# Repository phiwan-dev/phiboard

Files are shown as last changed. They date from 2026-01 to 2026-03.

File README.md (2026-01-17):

# phiboard
in progress, currently in the prototype phase...

# Third-Party Assets
### KiCad Symbols
The following Assets are from a third-party. Their original license still applies.
- Altium ISP1807-LR symbol in [`board/libraries/ISP1807-LR_Footprint.SchLib`](board/libraries/ISP1807-LR_Footprint.SchLib)
from the [manufacturers website](https://www.insightsip.com/products/bluetooth-le-modules/isp1807). There is no mention of a license.
- Kicad ISP1807-edit symbol in [`board/libraries/nordic-lib-kicad-isp1807.kicad_sym`](board/libraries/nordic-lib-kicad-isp1807.kicad_sym)
modified but based on the manufacturers symbol. Modifications follow this projects license (CERN-OHL-P-2.0).
- Kicad Nordic PMIC symbols in [`board/libraries/nordic-lib-kicad-npm.kicad_sym`](board/libraries/nordic-lib-kicad-npm.kicad_sym)
from https://github.com/hlord2000/nordic-lib-kicad using the CERN-OHL-P-2.0 license.
### KiCad Footprints
- Altium ISP1807-LR footprint in [`board/libraries/ISP1807-LR_Footprint.PcbLib`](board/libraries/ISP1807-LR_Footprint.PcbLib)
from the [manufacturers website](https://www.insightsip.com/products/bluetooth-le-modules/isp1807). There is no mention of a license.
- Kicad ISP1807-edit footprint in [`board/libraries/nordic-lib-kicad-isp1807.pretty`](board/libraries/nordic-lib-kicad-isp1807.pretty)
modified but based on the manufacturers symbol. Modifications follow this projects license (CERN-OHL-P-2.0).

<!-- ## Goals -->
<!-- - fully reversible pcb including hotswap sockets, MCU, OLED screen -->
<!-- - wireless using the XIAO BLE as MCU -->
<!-- - low profile (choc kailh) and thin PCB + components -->
<!-- - no visible screws from the top -->
<!-- - no visible seams from the top -->
<!-- - custom graphics and silk screen -->
<!-- - super easy, local zmk development -->

<!-- # Manual additions after Ergogen -->
<!-- Ergogen is used to generate most parts of the PCB. From within the ergogen folder, this can be done using: -->
<!-- ``` -->
<!-- ergogen . && cp output/pcbs/pcb.kicad_pcb ../kicad-prj/ -->
<!-- ``` -->
<!-- However, various smaller modifications as well as the reversible OLED and silkscreen graphics are placed manually by hand. -->
<!-- It is likely that this could be done through ergogen as well, feel free to fork and adjust my config. -->
<!-- All modifications are listed in here: -->
<!-- - Removed silksceens from diodes and modified silksceen for the battery pads. Be careful with this, as it make messing up the diode configuration very easy! -->
<!-- - Wired up MCU and keys in a reversible fashion -->
<!-- - Included reversible OLED --> 
<!-- - Put on silkscreens on front [`porsche-front-big.kicad_mod`](./kicad-prj/graphics.pretty/porsche-front-big.kicad_mod) and back [`porsche-back-big.kicad_mod`](./kicad-prj/graphics.pretty/porsche-back-big.kicad_mod) -->

<!-- # Customize Graphics -->
<!-- In [graphics](./kicad-prj/graphics/) you can find the source images used in this project. -->
<!-- There are two types of graphics. -->
<!-- ### Silkscreen -->
<!-- The silksceen uses the porsche images. -->
<!-- To use a different image you have to open `kicad > image converter`. -->
<!-- In here you can load your desired image, choose an output size and threshold and save it as footprint on F.Silkscreen. -->
<!-- In order for KiCad to detect your custom footprints, you have to save them to a folder with the extension `.pretty` like in [`kicad-prj/graphics.pretty/`](./kicad-prj/graphics.pretty/). -->
<!-- Lastly you need to tell KiCad where to find your footprints. -->
<!-- If you decide to use my project and its `graphics.pretty` folder then KiCad should automatically pick it up through the `fp-lib-table`. -->
<!-- Else, you can specify your `.pretty` path in `Preferences > Manage Footprint Libraries... > Project Specific Libraries`. -->
<!-- ### Solder Images -->
<!-- In the palm of the hand there is a little empty space on the PCB which I decided to use with images which are printed on there using solder. -->
<!-- I got the idea from [this video](https://www.youtube.com/watch?v=ohu4tZ4qov8). -->
<!-- Here is the workflow to put your own images on there: -->
<!-- You will most likely have a .png or .jpg image, which needs to be transformed to .svg. -->
<!-- For this you can use popular online tools like [convertio.co](https://convertio.co/). -->
<!-- Optionally you can try to optimize your svg using [this website](https://optimize.svgomg.net/), although it didn't make much of a difference for me. -->
<!-- Next, we need to transform our svg into an array of points, for which i used [this website](https://shinao.github.io/PathToPoints/). -->
<!-- Lastly, you can replace the point array in [`ergogen/footprints/phi-caps`](./ergogen/footprints/phi-caps.js) for the front side or [`ergogen/footprints/phi-logo`](./ergogen/footprints/phi-logo.js) for the back side. -->

<!-- # Parts -->
<!-- 40 keys, 20 per side -->
<!-- - 40 choc kailh switches -->
<!-- - 40 choc kailh keycaps -->
<!-- - 40 choc hotswap sockets -->
<!-- - 40 smd diodes 1N4148 -->
<!-- - 2 xiao ble -->
<!-- - 2 oled 0.91 inch i2c (optional) -->
<!-- - 2 batteries 3.7v (optional, requres cable otherwise) -->

<!-- # Firmware -->
<!-- Usually ZMK is compiled throug a GitHub actions workflow. However, I prefer to use it locally using a docker devcontainer. The devcontainer is provided by the official ZMK project. -->

<!-- ## Setting up the ZMK docker toolchain -->
<!-- ```bash -->
<!-- nix develop     # or install devcontainer cli otherwise -->
<!-- cd <path-to-phiboard>/firmware -->
<!-- ./setup-zmk.sh  # this may take a while -->
<!-- ``` -->

<!-- ## Compiling the ZMK firmware -->
<!-- ```bash -->
<!-- nix develop     # or install devcontainer cli otherwise -->
<!-- cd <path-to-phiboard>/firmware -->
<!-- ./build.sh  # clean build, is needed the first time -->
<!-- ./build.sh --cached   # faster, if a build has been done before -->
<!-- # the firmware is now located at <path-to-phiboard>/firmware/(left|right).uf2 -->
<!-- ``` -->

<!-- ## Flashing the firmware -->
<!-- - connect mcu with pc -->
<!-- - double press the reset button -->
<!-- - the file explorer should now show a usb media -->
<!-- - copy the corresponding .uf2 firmware to the usb media -->
<!-- - it should now auto-eject and run the new firmware -->

<!-- ## Fighting with ZMK -->
<!-- - spend a lot of time on local toolchain and scripts -->
<!-- - other projects may have their config files in different places -->
<!-- - explain most important files which the user might want to change (and where) -->
<!-- - confusing, overwhelming (at first) -->
<!-- - flash reset firmware to fix problems -->
<!-- - dtsi is "weird" because of the way the matrix is connected (only on prototype) -->
<!-- - right overlay columns are reversed because its mirrored but pcb is non-mirrored -->
<!-- - main half controls layers of secondary half -> perhaps need to flash both sides for keymap to take new changes -->
<!-- - displays have close to 0 documentation at all -->

<!-- # Soldering -->
<!-- - watch a solder intro video if you dont know what you are doing -->
<!-- - the second half will be better -->
<!-- - put solder on the pads, then heat the pads and press components in -->
<!-- - if possible, test connectivity from mcu to front pads -->
<!-- - care for diode direction (on prototype) -->

<!-- # Future fixes (from prototype) -->
<!-- - key spacing? -->
<!-- - different display -->

<!-- # Thanks -->
<!-- - to https://github.com/MvEerd/ergogen/tree/mveerd for ergogen -->
<!-- - to https://flatfootfox.com/ergogen-introduction/ for teaching ergogen -->
<!-- - to https://github.com/Pipshag/goosekb for inspiration on ergogen and zmk -->
<!-- - to https://www.youtube.com/watch?v=ohu4tZ4qov8 for finally making me follow through -->
<!-- - and many, many more! -->

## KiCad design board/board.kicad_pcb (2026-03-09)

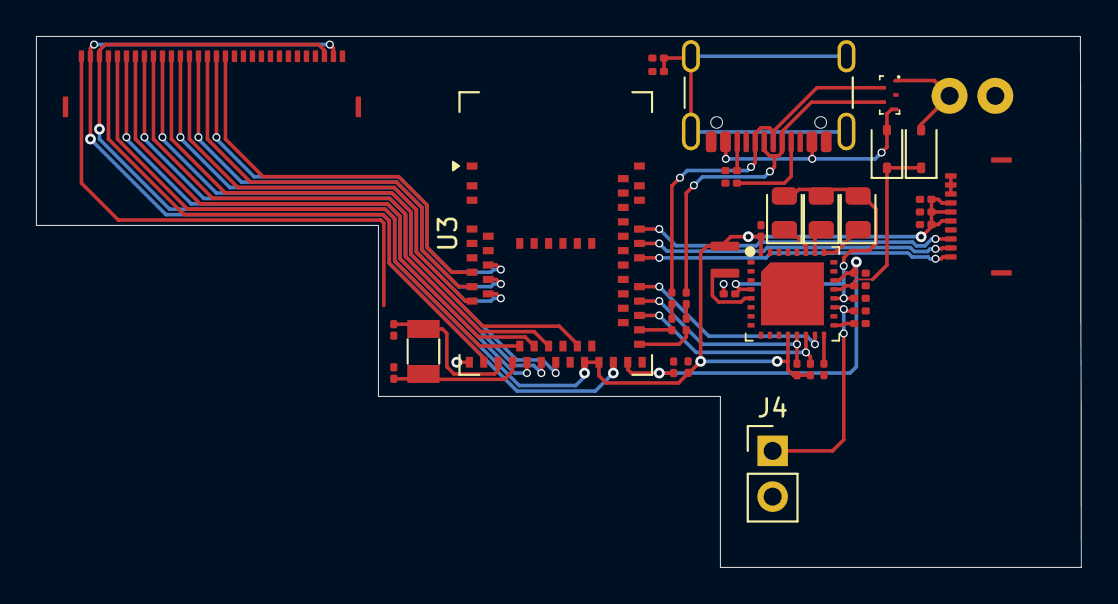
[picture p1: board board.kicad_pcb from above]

Board: 2 copper layers, 58.1 x 29.5 mm, 41 parts (1 on the bottom side), 55 nets.

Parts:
C2: 10nF; C_0201_0603Metric
C3, C4, C12, C14: 1uF; C_0201_0603Metric
C6: 470pF; C_0201_0603Metric
C7, C8: 12.5pF; C_0201_0603Metric
C9, C10, C15, C16, C17: 10uF; C_0201_0603Metric
C13: 2.2uF; C_0201_0603Metric
D3, D4: D_Schottky; D_SOD-323
D6, D7, D8: LED; LED_0805_2012Metric
J2: Conn_01x10; THD_0510-10CL-GF
J3: Conn_01x06; swd_pad
J4: Conn_01x02; PinHeader_1x02_P2.54mm_Vertical
J7: Conn_01x30; THD_0510-30CL-GF
J8: USB_C_Receptacle_USB2.0_16P; USB_C_Receptacle_GCT_USB4105-xx-A_16P_TopMnt_Horizontal
J9: Conn_01x02; magnetic connector 01x02P
L1: 2.2uH; L_0806_2016Metric
R4, R14: 5.1kR; R_0201_0603Metric
R5, R12, R13: 10kR; R_0201_0603Metric
R6, R7, R8, R9: 10R; R_0201_0603Metric
R10: 0R; R_0201_0603Metric
R11: 250-500kR; R_0201_0603Metric
U2: nPM1300-QEAA; nordic_npm1300-QEAA_qfn
U3: MDBT50Q-P1MV2; Raytac_MDBT50Q
U4: TVS_Array; DFN2010
Y1: 32k Hz; Crystal_SMD_3215-2Pin_3.2x1.5mm

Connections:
+1V8: J7.2, J7.29, U3.31 (DCCH)
+3V3: C3.1, C4.1, C6.1, C10.2, C17.1, J2.5, J2.6, J2.7, J3.2, J7.3, J7.28, L1.2, R12.1, R13.1, U2.12 (VDDIO), U2.32 (VOUT2), U3.28 (VDD), U3.30 (VDDH)
GND: C2.1, C3.2, C4.2, C6.2, C7.2, C8.2, C9.2, C10.1, C12.1, C13.2, C14.2, C15.2, C16.2, C17.2, J2.4, J2.8, J2.9, J2.10, J3.6, J4.2, J7.1, J7.30, J8.A1 (GND), J8.A12 (GND), J8.B1 (GND), J8.B12 (GND), J9.2, R4.1, R5.1, R10.1, R11.1, R14.1, U2.6 (PVSS2), U2.18 (NTC), U2.33 (AVSS), U3.1 (GND), U3.2 (GND), U3.15 (GND), U3.33 (GND), U3.55 (GND), U4.2 (GND)
unnamed: D3.2 (A), J8.A4 (VBUS), J8.A9 (VBUS), J8.B4 (VBUS), J8.B9 (VBUS), U4.3
unnamed: D4.2 (A), J9.1, U4.1
unnamed: D6.1 (K), U2.25 (LED0)
unnamed: D7.1 (K), U2.26 (LED1)
unnamed: D8.1 (K), U2.27 (LED2)
unnamed: J8.A5 (CC1), R4.2
unnamed: J8.B5 (CC2), R14.2
unnamed: C2.2, J8.S1 (SHIELD), R5.2
unnamed: R6.1, R7.2
unnamed: R8.1, R9.2
unnamed: L1.1, U2.5 (SW2)
unnamed: R10.2, U2.17 (VSET1)
unnamed: R11.2, U2.16 (VSET2)
unnamed: R8.2, U3.35 (D+)
unnamed: R6.2, U3.34 (D-)
unnamed: C8.1, U3.17 (P0.00), Y1.1
unnamed: C7.1, U3.18 (P0.01), Y1.2
key1: J7.4, U3.16 (P0.27)
key2: J7.5, U3.19 (P0.26)
key3: J7.6, U3.20 (P0.04)
key4: J7.7, U3.21 (P0.05)
key5: J7.8, U3.22 (P0.06)
key6: J7.9, U3.23 (P0.07)
key7: J7.10, U3.24 (P0.08)
key8: J7.11, U3.27 (P0.11)
key9: J7.12, U3.13 (P0.28)
key10: J7.13, U3.14 (P0.30)
key11: J7.14, U3.11 (P0.02)
key12: J7.15, U3.12 (P0.31)
key13: J7.16, U3.9 (P0.03)
key14: J7.17, U3.10 (P0.29)
key18: J7.21, U3.42 (P0.19)
key19: J7.22, U3.43 (P0.21)
key20: J7.23, U3.45 (P0.23)
key21: J7.24, U3.49 (P0.25)
key22: J7.25, U3.52 (P0.09)
key23: J7.26, U3.54 (P0.10)
nreset: J3.5, U3.40 (P0.18)
scl: R13.2, U2.14 (SCL), U3.37 (P0.13)
sclk: J2.1, U3.44 (P0.20)
scs: J2.3, U3.48 (P0.24)
sda: R12.2, U2.13 (SDA), U3.39 (P0.15)
shphld: U2.15 (SHPHLD), U3.41 (P0.17)
si: J2.2, U3.46 (P0.22)
swd_clk: J3.4, U3.53 (SWDCLK)
swd_data: J3.3, U3.51 (SWDIO)
usbd+: J8.A6 (D+), J8.B6 (D+), R9.1, U4.5
usbd-: J8.A7 (D-), J8.B7 (D-), R7.1, U4.4
vbat: C13.1, J4.1, U2.19 (VBAT)
vbus: C9.1, C14.1, U2.22 (VBUSOUT), U3.32 (VBUS)
vbus_raw: C12.2, D3.1 (K), D4.1 (K), U2.21 (VBUS)
vsys: C15.1, C16.1, D6.2 (A), D7.2 (A), D8.2 (A), U2.4 (PVDD), U2.20 (VSYS)

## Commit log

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2025-06-06 fix: remove mirror attribute in favor of reversable pcb
2025-06-06 dev: add pcb with reverse hotswap choc switches
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2025-06-09 dev: add output files
    [board.dxf, combined.dxf, keys.dxf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]
2025-06-09 dev: remove diode silkscreens
    [pcb.kicad_pcb]
2025-06-09 dev: wired up mcu pads on pcb
    [pcb.kicad_pcb]
2025-06-09 dev: wire up key matrix
    [pcb.kicad_pcb]
2025-06-09 dev: include reversible oled screen
    [pcb.kicad_pcb]
2025-06-10 dev: add kicad outputs
    [pcb-B_Cu.gbr, pcb-B_Mask.gbr, pcb-B_Paste.gbr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]
2025-07-20 fix: restructure project into distinct ergogen, kicad and zmk folders
    [board.dxf, combined.dxf, keys.dxf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]
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2026-01-10 ergogen: remove files because they are unused now
    [board.dxf, combined.dxf, keys.dxf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]
2026-01-10 other: remove prototype kicad files
    [pcb-B_Cu.gbr, pcb-B_Mask.gbr, pcb-B_Paste.gbr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]
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2026-01-12 board: add manufacturer isp1807 symbol
    [ISP1807-LR_Footprint.SchLib]
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2026-01-14 board: pmic add usb
    [board.kicad_sch]
2026-01-14 board: pmic add led and gpio
    [board.kicad_sch]
2026-01-14 board: pmic add twi
    [board.kicad_sch]
2026-01-14 baord: pmic add buck1
    [board.kicad_sch]
2026-01-14 board: pmic add buck2 and disable ldo1+2
    [board.kicad_sch]
2026-01-14 board: pmic add battery management
    [board.kicad_sch]
2026-01-15 board: display add cable
    [board.kicad_sch]
2026-01-15 board: display add power delivery net
    [board.kicad_sch]
2026-01-15 board: sch display add extmode and extcomin
    [board.kicad_sch]
2026-01-15 board: sch display add disp signal
    [board.kicad_sch]
2026-01-15 board: sch board to board connector
    [board.kicad_sch]
2026-01-15 board: sch internal usb connector
    [board.kicad_sch]
2026-01-15 board: sch tidy up and battery connector
    [board.kicad_sch]
2026-01-15 board: sch add mcu
    [board.kicad_sch]
2026-01-15 board: sch mcu connect power
    [board.kicad_sch]
2026-01-16 board: sch configure vusb
    [board.kicad_sch]
2026-01-16 board: sch configure swd
    [board.kicad_sch]
2026-01-16 board: sch mcu gpio
    [board.kicad_sch]
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2026-02-03 board: try different footprint placements
    [board.kicad_pcb]
2026-02-03 board: outline key matrix in pcb
    [board.kicad_pcb]
2026-02-03 board: change outline to flat 19 mm spacing (instead of 19.05 mm)
    [board.kicad_pcb]
2026-02-11 board: start rough footprint placement
    [board.kicad_pcb]
2026-02-11 board: start move to raytac MDBT50Q-1MV2 instead of isp1807
    [board.kicad_sch]
2026-02-11 board: add normal voltage mode to raytac module
    [board.kicad_sch]
2026-02-11 board: add data lines to raytac module
    [board.kicad_sch]
2026-02-11 board: sch add external 32k crystal
    [board.kicad_sch]
2026-02-12 board: sch move power circuitry from pmic to raytac module
    [board.kicad_sch]
2026-02-13 board: sch add spi to nrf
    [board.kicad_sch]
2026-02-13 board: sch remove unused isp1807
    [board.kicad_sch]
2026-02-14 board: sch change board connector to 1x30 instead of 1x20 to include power lanes
    [board.kicad_sch]
2026-02-16 board: sch add footprints for R and C and for C LCSC PN number
    [board.kicad_sch]
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2026-02-16 board: sch add led footprint plus lcsc pn
    [board.kicad_sch]
2026-02-16 board: sch add r lcsc pn
    [board.kicad_sch]
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2026-02-19 board: sch move to power circuit to new symbol
    [board.kicad_sch]
2026-02-20 board: pcb fix naming and pad number
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2026-02-21 board: sch L add lcsc pn and footprint
    [board.kicad_sch]
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2026-02-22 board: sch crystal add lcsc pn and footprint
    [board.kicad_sch]
2026-02-22 board: sch fix swd connect with new footprint
    [board.kicad_sch]
2026-02-22 board: sch tidy up display connector
    [board.kicad_sch]
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2026-02-22 board: sch assign display connector new ffc connector footprint and lcsc pn
    [board.kicad_sch]
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2026-02-24 board: sch assign footprint to board to board connector
    [board.kicad_sch]
2026-02-24 board: sch add footprint and lcsc pn to npm1300
    [board.kicad_sch]
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2026-02-25 board: sch add battery pad
    [board.kicad_sch]
2026-02-25 board: sch add usb c to magnet adapter
    [board.kicad_sch]
2026-02-26 board: sch add usb circuit
    [board.kicad_sch]
2026-02-27 board: sch add emi protection
    [board.kicad_sch]
2026-02-27 board: pcb rough footprint placement
    [board.kicad_pcb]
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2026-02-27 board: sch add usb receptacle lcsc pn and footprint
    [board.kicad_sch]
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2026-02-27 board: sch add esd protection
    [board.kicad_sch]
2026-02-28 board: sch add mounting pin to ffc connectors
    [board.kicad_sch]
2026-02-28 board: pcb re-link footprints
    [board.kicad_pcb]
2026-02-28 board: pcb add i2c and fix spi
    [board.kicad_sch]
2026-02-28 board: sch add keys
    [board.kicad_sch]
2026-02-28 board: sch add shphld
    [board.kicad_sch]
2026-02-28 board: sch display correct capacitor configuration
    [board.kicad_sch]
2026-03-01 board: sch fix remaining part numbers and key placement
    [board.kicad_sch]
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2026-03-02 board: sch remove unpopulated components from schematic
    [board.kicad_sch]
2026-03-03 board: pcb move components to approximate location
    [board.kicad_pcb]
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2026-03-04 board: pcb fix courtyard and orientation silkscreen for footprints
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2026-03-05 board: sch fix tvs diode array symbol
2026-03-05 board: sch change tvs diode array to BDFN2010A054R
    [board.kicad_sch]
2026-03-05 board: sch fix usb cc1/2 pins to 5.1kR
    [board.kicad_sch]
2026-03-05 board: sch change schottky diodes to smaller footprint
    [board.kicad_sch]
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2026-03-07 board: pcb move components and traces extending over the edge
    [board.kicad_pcb]
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2026-03-08 board: sch change case grounding resistor from 300kR to 10kR
    [board.kicad_sch]
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2026-03-09 board: pcb reroute bottom front keys with changed power order
    [board.kicad_pcb]
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2026-03-09 board: sch change left key pins assignment to better match connector
    [board.kicad_pcb, board.kicad_sch]
